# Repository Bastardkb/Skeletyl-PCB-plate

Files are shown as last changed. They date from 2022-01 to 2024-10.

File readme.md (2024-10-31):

# Skeletyl PCB - plate

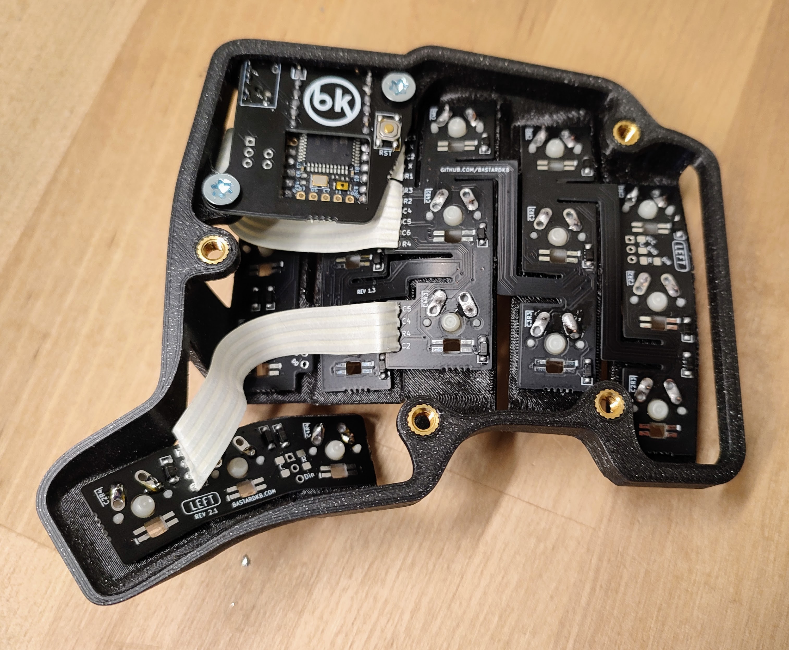
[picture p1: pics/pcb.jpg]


Flexible PCB made for the Skeletyl.

With per-key RGB.

This repository contains all files necessary to order a PCB.

If you want to modify the design files, the Kicad sources are included.
If you just want to order the PCBs, check out the Release section which contain the gerber files.

## How to order

Order with a 0.6mm or 0.8mm PCB thickness

## License

Licensed under CC BY-NC-SA 4.0
Copyright Quentin Lebastard 2021

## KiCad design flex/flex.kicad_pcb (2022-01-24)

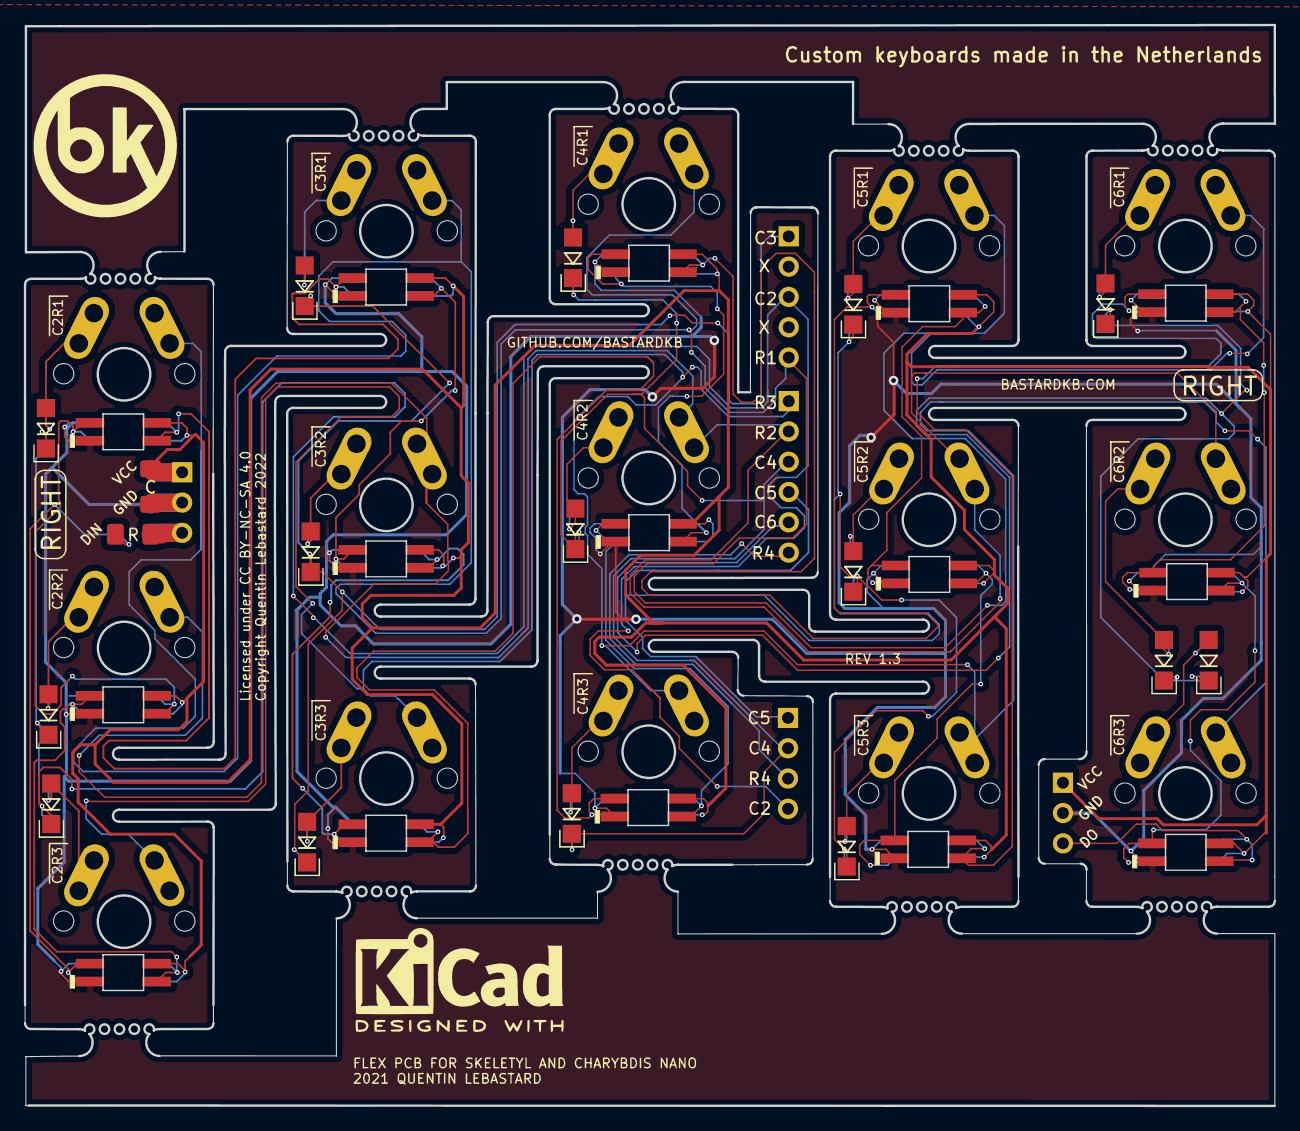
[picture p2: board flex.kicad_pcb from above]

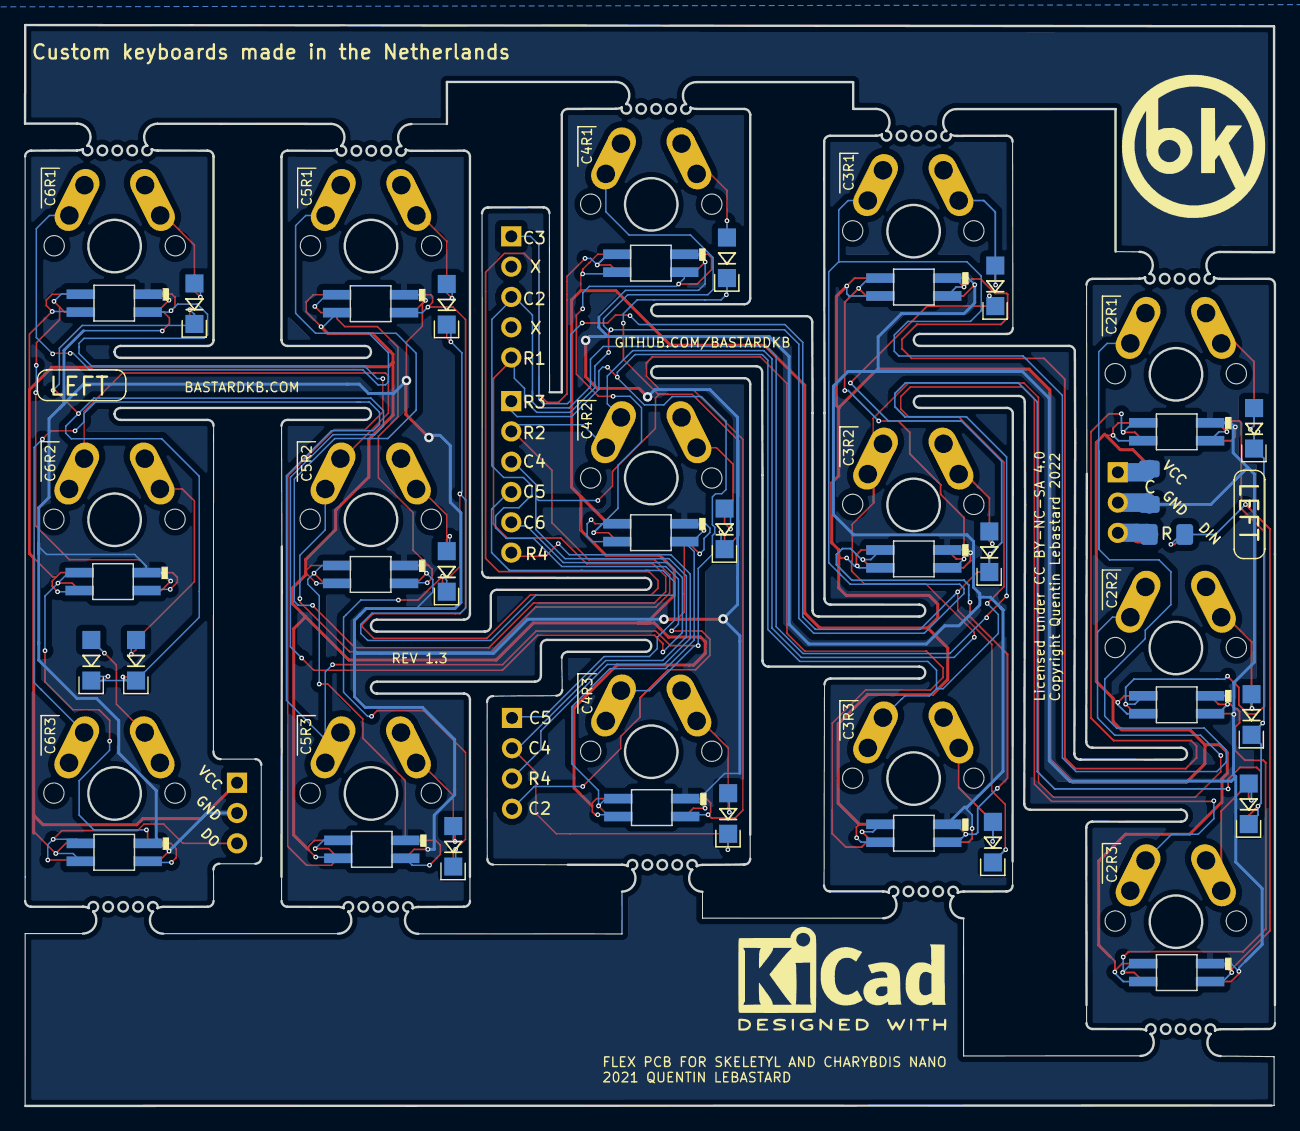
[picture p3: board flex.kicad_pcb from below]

Board: 2 copper layers, 104.8 x 90.6 mm, 69 parts (32 on the bottom side), 43 nets.

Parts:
C1, C2: C; C_1206_3216Metric_Pad1.42x1.75mm_HandSolder
D5, D7, D21, D23, D25, D33, D37, D39, D41, D47, D49, D51, D55, D57, D59: SK6812MINI; YS-SK6812MINI-E_REVERSE
D6, D8, D22, D24, D26, D34, D38, D40, D42, D48, D50, D52, D56, D58, D60: SK6812MINI; YS-SK6812MINI-E_REVERSE_NO_EDGECUT
D9, D11, D12, D13, D14, D15, D16, D17, D19, D20, D27, D31, D32, D35, D36: D; Diode_TH_SOD123
J1: Conn_01x04_Female; PinHeader_1x04_P2.54mm_Vertical
J2: Conn_01x05_Female; PinHeader_1x05_P2.54mm_Vertical
J3, J5: Conn_01x03_Female; PinHeader_1x03_P2.54mm_Vertical
J4: Conn_01x06_Female; PinHeader_1x06_P2.54mm_Vertical
R1, R2: R; R_1206_3216Metric_Pad1.42x1.75mm_HandSolder
SW6, SW7, SW8, SW10, SW11, SW12, SW15, SW16, SW17, SW20, SW21, SW22, SW24, SW25, SW26: SW_Push; SW_MX_reversible

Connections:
Din: J3.3, R1.1, R2.1
Dout: D59.1 (DOUT), D60.1 (DOUT), J5.3
Gnd: C1.2, C2.2, D5.2 (VSS), D6.2 (VSS), D7.2 (VSS), D8.2 (VSS), D21.2 (VSS), D22.2 (VSS), D23.2 (VSS), D24.2 (VSS), D25.2 (VSS), D26.2 (VSS), D33.2 (VSS), D34.2 (VSS), D37.2 (VSS), D38.2 (VSS), D39.2 (VSS), D40.2 (VSS), D41.2 (VSS), D42.2 (VSS), D47.2 (VSS), D48.2 (VSS), D49.2 (VSS), D50.2 (VSS), D51.2 (VSS), D52.2 (VSS), D55.2 (VSS), D56.2 (VSS), D57.2 (VSS), D58.2 (VSS), D59.2 (VSS), D60.2 (VSS), J3.2, J5.2
unnamed: D5.1 (DOUT), D6.1 (DOUT), D7.3 (DIN), D8.3 (DIN)
unnamed: D5.3 (DIN), D6.3 (DIN), R1.2, R2.2
unnamed: D9.2 (A), SW6.2
unnamed: D11.2 (A), SW10.2
unnamed: D12.2 (A), SW8.2
unnamed: D13.2 (A), SW15.2
unnamed: D14.2 (A), SW20.2
unnamed: D15.2 (A), SW7.2
unnamed: D16.2 (A), SW24.2
unnamed: D17.2 (A), SW12.2
unnamed: D19.2 (A), SW11.2
unnamed: D20.2 (A), SW17.2
unnamed: D21.1 (DOUT), D22.1 (DOUT), D23.3 (DIN), D24.3 (DIN)
unnamed: D21.3 (DIN), D22.3 (DIN), D33.1 (DOUT), D34.1 (DOUT)
unnamed: D23.1 (DOUT), D24.1 (DOUT), D25.3 (DIN), D26.3 (DIN)
unnamed: D25.1 (DOUT), D26.1 (DOUT), D37.3 (DIN), D38.3 (DIN)
unnamed: D27.2 (A), SW16.2
unnamed: D31.2 (A), SW22.2
unnamed: D32.2 (A), SW21.2
unnamed: D7.1 (DOUT), D8.1 (DOUT), D33.3 (DIN), D34.3 (DIN)
unnamed: D35.2 (A), SW26.2
unnamed: D36.2 (A), SW25.2
unnamed: D37.1 (DOUT), D38.1 (DOUT), D39.3 (DIN), D40.3 (DIN)
unnamed: D39.1 (DOUT), D40.1 (DOUT), D41.3 (DIN), D42.3 (DIN)
unnamed: D41.1 (DOUT), D42.1 (DOUT), D47.3 (DIN), D48.3 (DIN)
unnamed: D47.1 (DOUT), D48.1 (DOUT), D49.3 (DIN), D50.3 (DIN)
unnamed: D49.1 (DOUT), D50.1 (DOUT), D51.3 (DIN), D52.3 (DIN)
unnamed: D51.1 (DOUT), D52.1 (DOUT), D55.3 (DIN), D56.3 (DIN)
unnamed: D55.1 (DOUT), D56.1 (DOUT), D57.3 (DIN), D58.3 (DIN)
unnamed: D57.1 (DOUT), D58.1 (DOUT), D59.3 (DIN), D60.3 (DIN)
Vcc: C1.1, C2.1, D5.4 (VDD), D6.4 (VDD), D7.4 (VDD), D8.4 (VDD), D21.4 (VDD), D22.4 (VDD), D23.4 (VDD), D24.4 (VDD), D25.4 (VDD), D26.4 (VDD), D33.4 (VDD), D34.4 (VDD), D37.4 (VDD), D38.4 (VDD), D39.4 (VDD), D40.4 (VDD), D41.4 (VDD), D42.4 (VDD), D47.4 (VDD), D48.4 (VDD), D49.4 (VDD), D50.4 (VDD), D51.4 (VDD), D52.4 (VDD), D55.4 (VDD), D56.4 (VDD), D57.4 (VDD), D58.4 (VDD), D59.4 (VDD), D60.4 (VDD), J3.1, J5.1
col2: D9.1 (K), D12.1 (K), D15.1 (K), J1.4, J2.3
col3: D11.1 (K), D17.1 (K), D19.1 (K), J2.1
col4: D13.1 (K), D20.1 (K), D27.1 (K), J1.2, J4.3
col5: D14.1 (K), D31.1 (K), D32.1 (K), J1.1, J4.4
col6: D16.1 (K), D35.1 (K), D36.1 (K), J4.5
row2: J2.5, SW6.1, SW10.1, SW15.1, SW20.1, SW24.1
row3: J4.2, SW7.1, SW11.1, SW16.1, SW21.1, SW25.1
row4: J4.1, SW8.1, SW12.1, SW17.1, SW22.1, SW26.1
row5: J1.3, J4.6

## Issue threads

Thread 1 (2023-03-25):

assembled version

bstiq, 2023-03-25:
- [x] new edge cuts
- [x] thinner columns
- [x] rounded extremities
- [x] space for assembled footprints
- [x]  same rgb footprint as 4x6
- [x] fix trace settings - 0.13 and 0.3 per net, clearances as well. Double check with JLC 2 layer
- [x] rgb: move middle vias away from middle... causing shorts...
- [x] use 0402 or 0201 diodes, in clusters - eg. sod523 (C122862)
- [x] make diodes reversible to enable double-sided RGB assembly
- [ ] move files to `assembled` folder
- [x] emergency 1206 diodes on top of each switch
- [x] cleanup
- [ ] ~~remove panel cuts~~
- [ ] ~~pcb art ?~~
- [ ] ~~add led numbers ?~~
- [x] bigger thermal reliefs for leds
- [x] change silkscreen fonts to fira sans
- [x] add very visible top/bottom labels for easier assembly
- [x] make emergency diodes footprint slightly smaller
- [x] add detrompeur to outside of emergency diode footprint
- [x] place assembled capacitors
- [x] place assembled resistors
- [x] fix row numbering

bstiq, 2023-05-16:
strategy for assembly:

- [ ] keep existing diodes, rename as NA, mark as non-bom
- [ ] make it look nicer in schem
- [ ] copy paste into D_LEFT_xx, D_RIGHT_xx (same for resistor, capacitor, leds etc)

Closed 2023-08-15.

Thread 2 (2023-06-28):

issues with assembled version

bstiq, 2023-06-28:
- trace for C4 broken between thumb cluster and main plate connection
- trace for R2 broken between row and main plate connector

bstiq, 2023-06-30:
PCB tends to break here:
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

Closed 2023-10-24.

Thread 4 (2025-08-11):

V3

bstiq, 2025-08-11:
- [ ] solidify ribbon cable connection
- [ ] switch to 1206 diodes, make them bigger (like on old PCB)
- [ ] ?horizontal diodes?
- [ ] ~~double diode footprint (for assembly)~~
- [ ] new rgb led footprints (with GND + pin 1 marking)
- [ ] north facing RGB
- [ ] update copyright text on PCB
- [ ] check mouse bites // interference with top leds
- [ ] check led placement // interference with case
- [ ] move column/row switch numbering
- [ ] hatched zone
- [ ] label diode row/cols
- [ ] ~~FPC connector?~~
- [ ] ~~add column tht connector for bodge on each column, same with rows?~~
- [ ] ~~silkscreen: move C and R next to diode switch silkscreen indicator~~
- [ ] check led placement with JLC
- [ ] re route with JLC minimum trace and VIA capabilities (check 4x6!)
- [ ] new mouse bites with drill holes!
- [ ] bigger white lines on diodes for direction

Others:

- [ ] bigger PCB columns to accomodate traces
- [ ] slightly wider traces

- [ ] add tht pads for each led pins
- [ ] add tht pads for columns near diodes
- [ ] make breaking-prone traces more solid

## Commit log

2022-01-24 add stuff
    [flex.kicad_pcb, flex.kicad_sch]
2024-12-06 move top edge cuts for led

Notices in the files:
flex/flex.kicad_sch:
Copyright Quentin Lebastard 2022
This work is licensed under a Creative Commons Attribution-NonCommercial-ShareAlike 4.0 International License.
